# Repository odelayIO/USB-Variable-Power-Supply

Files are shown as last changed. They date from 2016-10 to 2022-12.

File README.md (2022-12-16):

##### View on [gh-page](https://odelayio.github.io/USB-Variable-Power-Supply/)

# USB Variable Power Supply based on the LM317 Device

## Board Features:

- Variable Output Power between 1.8V to 5V
-	VCC Set by Resistors (0805 Package)
- LED for VCC and +5V Power Rail
-	Header Pin for +5V Output 

<br>
<br>

Layout

<br>
<br>
   
<br>
<br>

## Parts List

| Part | Part Number | Unit Price | Notes | Link |
|---|--- |---|---|---|
| USB Mini Connector | 151-1206-1-ND | $6.55 | 10 Connectors | http://www.digikey.com/product-detail/en/edac-inc/690-005-299-043/151-1206-1-ND/4312192 |
| LM317 | 768-1008-1-ND | $0.77 | In stock | http://www.digikey.com/product-detail/en/texas-instruments/LM317DCYR/296-12602-1-ND/443738 |
| 0.1uF, 0402, Cap | 490-6328-1-ND | $0.55 | 100 capacitor | http://www.digikey.com/product-detail/en/murata-electronics-north-america/GRM155R71C104KA88J/490-6328-1-ND/3845525 |
| 10uF, 0805, Cap | 1276-6456-1-ND | $0.78 | 10 capacitor  | http://www.digikey.com/product-detail/en/samsung-electro-mechanics-america-inc/CL21A106KPFNNNG/1276-6456-1-ND/5958084 |
| 143 ohm, 0402 | YAG2980CT-ND | $0.48 | 100 resistors | http://www.digikey.com/product-detail/en/yageo/RC0402FR-07143RL/YAG2980CT-ND/5281845 |
| 240 ohm, 0402 | RMCF0805JT240RCT-ND | $0.67 | 100 resistors | http://www.digikey.com/product-detail/en/stackpole-electronics-inc/RMCF0805JT240R/RMCF0805JT240RCT-ND/1942545 |
| 392 ohm, 0402 | 311-392CRCT-ND | $0.87 | 100 resistors | http://www.digikey.com/product-detail/en/yageo/RC0805FR-07392RL/311-392CRCT-ND/730851 |
| 1uF, 0402 Cap | 490-1320-1-ND | $0.96 | 100 capacitor | http://www.digikey.com/product-detail/en/murata-electronics-north-america/GRM155R60J105KE19D/490-1320-1-ND/587919 |
| Red LED | SML-D12V1WT86CT-ND | $1.71 | 10 LEDs | http://www.digikey.com/product-detail/en/rohm-semiconductor/SML-D12V1WT86/SML-D12V1WT86CT-ND/5843857 |
| Yellow/Green LED | SML-D12M1WT86CT-ND | $1.71 | 10 LEDs | http://www.digikey.com/product-detail/en/rohm-semiconductor/SML-D12M1WT86/SML-D12M1WT86CT-ND/5843861 |
| PCB Fab | 2 layer prototype | $5.00 | 3 copies | http://docs.oshpark.com/services/two-layer/ |
| | | | | |

<br>
<br>

## Additional Information:
- Fab board at [https://oshpark.com/](https://oshpark.com/)
  - Gerber Zip Package was used to fab board

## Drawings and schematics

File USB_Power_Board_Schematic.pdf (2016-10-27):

A

A

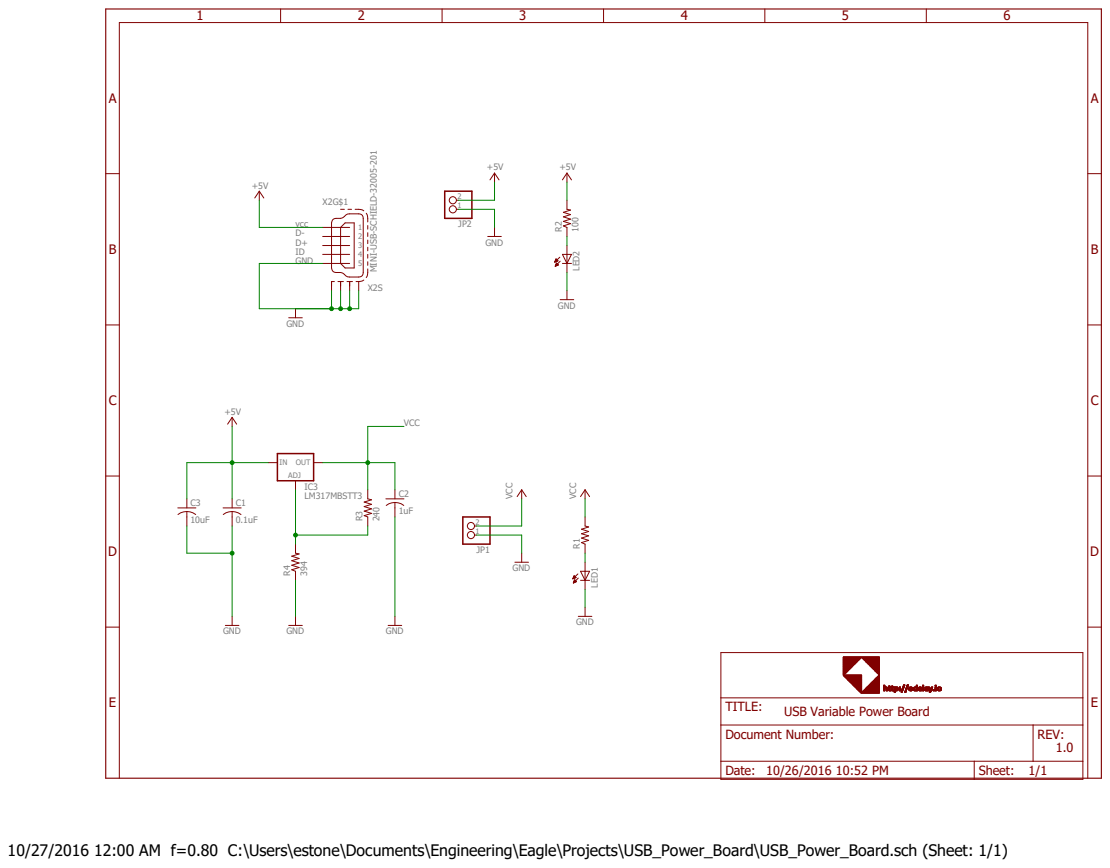
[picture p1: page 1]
LM317MBSTT3; 394 GND; +5V GND; GND; IC3 ADJ; IN OUT; LED¹ LED²; vcc D- D+; ID GND; VCC; TITLE:

+5V VCC MINI-USB⁻SCHIELD⁻³²⁰⁰⁵⁻²⁰¹ GND +5V
+5VVCC GND

USB Variable Power Board

Document Number: | REV: 1.0

Date: 10/26/2016 10:52 PM | Sheet: 1/1

10/27/2016 12:00 AM f=0.80 C:\Users\estone\Documents\Engineering\Eagle\Projects\USB_Power_Board\USB_Power_Board.sch (Sheet: 1/1)

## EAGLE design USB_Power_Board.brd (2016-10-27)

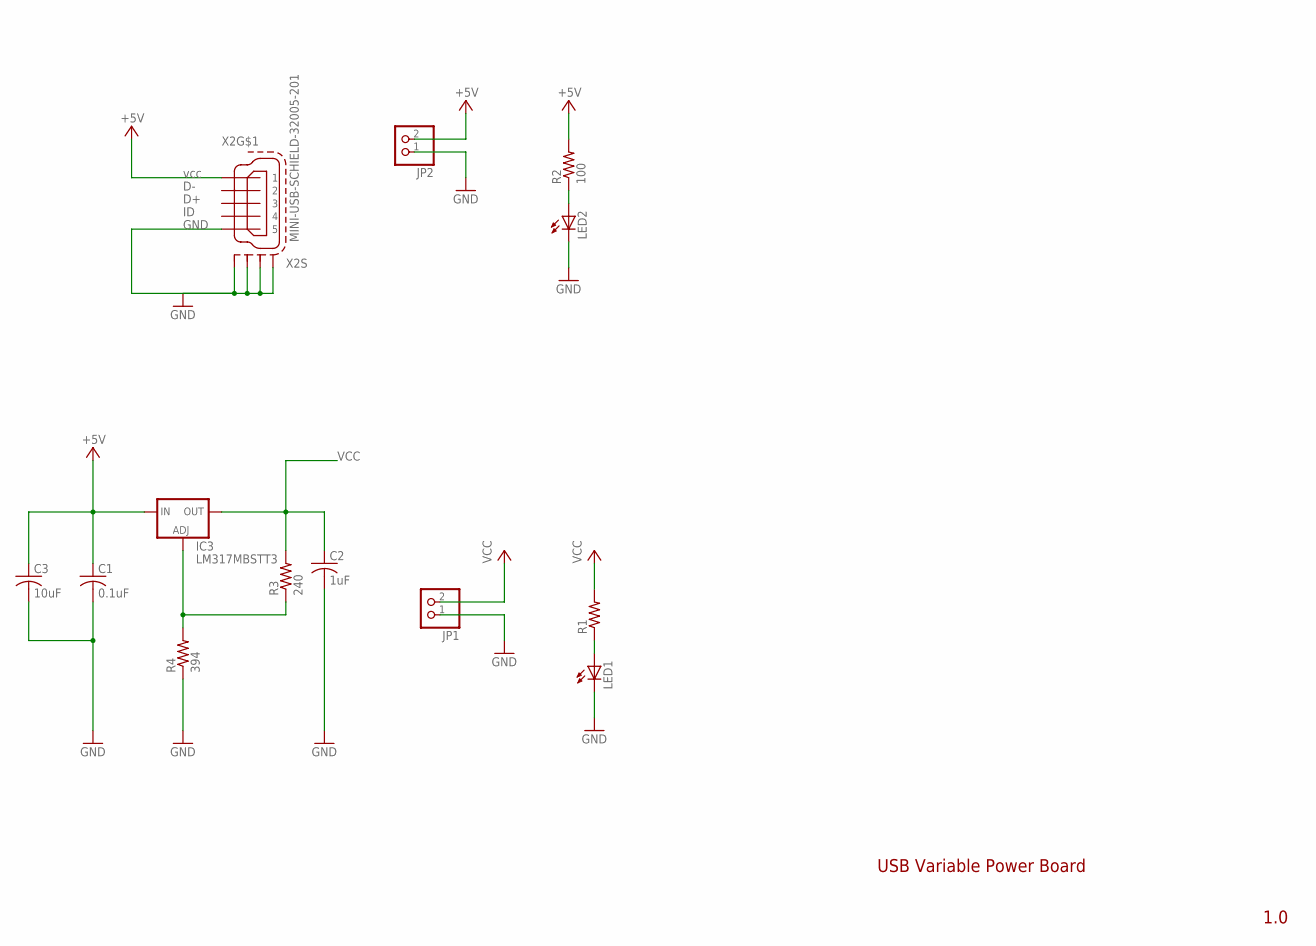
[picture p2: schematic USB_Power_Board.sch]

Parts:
C1: 0.1uF; C0402
C2: 1uF; C0402
C3: 10uF; C0603
IC3: LM317MBSTT3; SOT223
JP1, JP2: PINHD-1X2; 1X02
LED1, LED2: LEDCHIP-LED0603; CHIP-LED0603
R1: R-US_R0402; R0402
R2: 100; R0402
R3: 240; R0805
R4: 394; R0805
X2: MINI-USB-SCHIELD-32005-201; 32005-201

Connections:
+5V: C1.1, C3.1, IC3.3 (IN), JP2.2, R2.2, X2.1
GND: C1.2, C2.2, C3.2, JP1.1, JP2.1, LED1.C, LED2.C, R4.1, X2.5, X2.M1 (S1), X2.M2 (S2), X2.M3 (S3), X2.M4 (S4)
unnamed: LED1.A, R1.1
unnamed: IC3.1 (ADJ), R3.1, R4.2
unnamed: LED2.A, R2.1
VCC: C2.1, IC3.4 (OUT), JP1.2, R1.2, R3.2

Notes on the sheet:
USB Variable Power Board
1.0

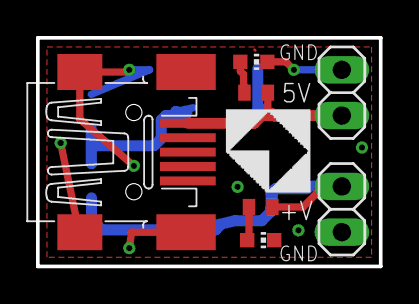
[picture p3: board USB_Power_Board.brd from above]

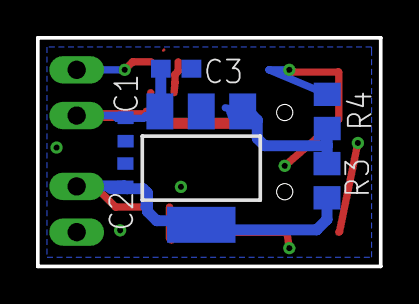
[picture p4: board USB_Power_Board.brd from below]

Board: 2 copper layers, 19.1 x 12.7 mm, 13 parts (6 on the bottom side), 6 nets.
